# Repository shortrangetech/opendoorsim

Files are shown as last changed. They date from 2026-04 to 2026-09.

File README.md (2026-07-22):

# OpenDoorSim — Personal RFID Lab

<p align="center">
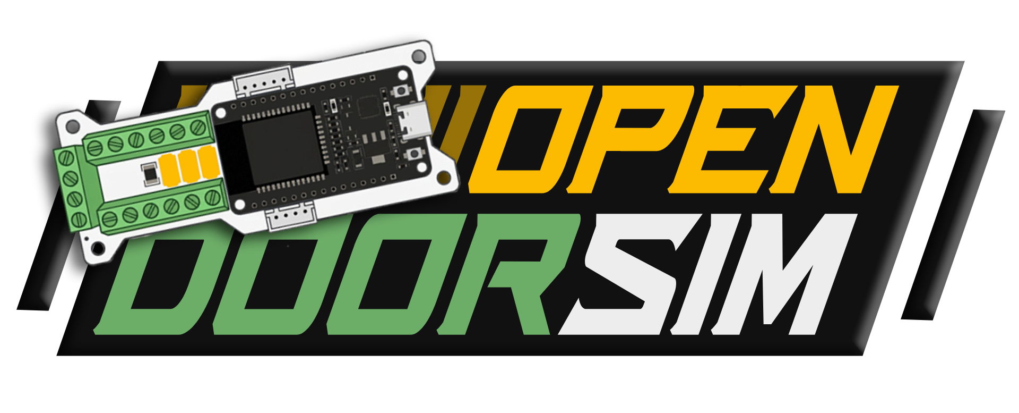
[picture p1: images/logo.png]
OpenDoorSim Logo
    
</p>

> [!NOTE]
> 
> 🚧 README and Documentation are under construction! Full documentation and links are being released incrementally through August. Check back for updates. 🚧

OpenDoorSim is your personal **open-source PACS / RFID lab!**. OpenDoorSim simulates Physical Access Control Systems (PACS) by connecting to real readers, so you can **hack the real thing!** At-home experiments, big CTFs, hands-on workshops, banger demos and advanced research are a breeze! It works with **any Wiegand or (soon) OSDP reader**, and fits easily in your bag. Sporting a **fresh web UI with a mirrored virtual display**, an **on-device hardware menu**, and multiple **modes** to make life easy, you may find it hard to put down... 

<p align="center">
  <a href="#">Documentation</a> · <a href="#">Build Guide</a> · <a href="#">Firmware Guide</a> · <a href="#">User Guide</a>
</p>
<p align="center">
  <a href="https://shortrange.tech">Support the Project - Buy an Official Kit!</a> · <a href="#">Self-Manufacture</a>
</p>

## Features

- Use any Wiegand or (soon) OSDP reader!
- Powered by 5V USB-C
- Beautiful Web UI for displaying data, managing users and modifying settings
- Handy on-device Menu for offline operations
- Multi Mode (Raw, User, Wifi, Stealth, Tamper Detect, etc)
- Live Virtual Display for easy demos
- Rugged 3D printed case
- Batch User Management

<p align="center">
  <a href="https://youtu.be/uSH2qY0MCnA">
    OpenDoorSim Demo Video<br>
    <sub>▶️ Click here to watch the demo video on YouTube</sub>
  </a>
</p>

## Quick start

For starters -- you'll need at minimum an OpenDoorSim (ODS) Board and a reader. You can manufacture your own PCBs using the project files, or buy an official PCB completely assembled and pre-flashed at [shortrange.tech](https://shortrange.tech). The card reader is up to you -- buy one from ebay, borrow one from work, etc...

Once you have an ODS board and reader, plug the reader's data and power lines into the board, and then power it via 5V USB-C. Connect to the OpenDoorSim's Wifi SSID and navigate to 192.168.8.8 to interact with the web UI. Now, you're ready to begin scanning!

You may want to add a physical screen, knob, and protective case to physically interact with your OpenDoorSim beyond the web UI. Upgrades, people! Again, you can purchase / build these yourself using the project files and Bill of Materials, or buy as part of an official kit. 

Once you have the parts you need from the BOM, follow the official [build guide](#).

For full details on the project, please visit the [Official Documentation](#).

Finally, make sure to tell your friends about the project!

<p align="center">
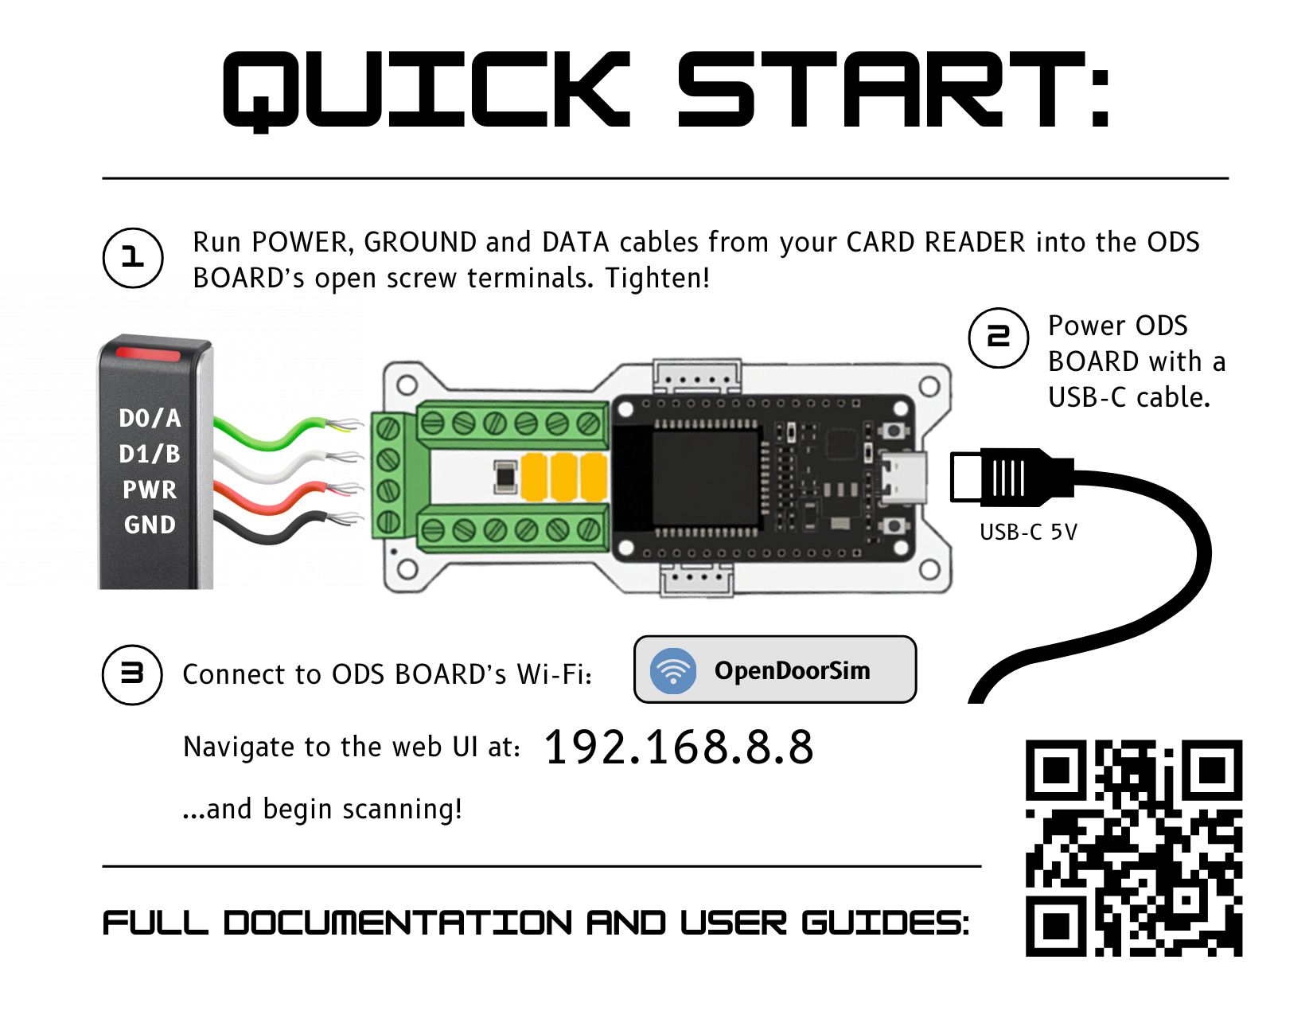
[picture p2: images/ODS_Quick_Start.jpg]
QuickStart Guide
    
</p>

## Support the Project

There are so many ways to support the project! Here are a few:
- Tell your friends about OpenDoorSim!
- Use your OpenDoorSim!
- Get your parts from the official BOM!
- Star the repository!
- Buy an [official kit!](https://shortrange.tech).

## Licenses and Agreements

This project is licensed under GPLv3.

**GPLv3 License**
This program is free software: you can freely use, modify, and distribute it. If you distribute your version, you must do so under the same GNU General Public License Version 3 (GPLv3) and include the source code. The software is provided without warranty, and the authors are not liable for damages.

See [LICENSE](LICENSE) for more details.

## Acknowledgments

This project was initially based on and greatly inspired by evildaemond's [DoorSim project](https://github.com/evildaemond/doorsim), without which this project would likely not exist, or at least have materialized nearly as soon as it did. 

Thanks to nechry for his [PlatformIO refactoring fork](https://github.com/nechry/DoorSim) of evildaemond's original DoorSim project. It was a great base to work from and LittleFS as well as PlatformIO really saved the day on development.  

A big thank you to the incredible students, hackers, professionals, and mentors in Iceman's Discord community [RFID Hacking By Iceman](https://discord.gg/F6wwKj6BHr), and to Iceman for his support. You all inspire me.  

Thank you to all other open source creators and mentors who are doing inspiring work in the field of PACS / RFID / RF! **Let's Hack The Planet!**

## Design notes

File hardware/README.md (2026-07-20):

# OpenDoorSim Hardware Guide

Welcome to the hardware folder for OpenDoorSim! This folder has the PCB manufacturing files, 3D models and schematics for the OpenDoorSim.

*For full instructions, please refer to the [Official Documentation](#).*

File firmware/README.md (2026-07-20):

# OpenDoorSim Firmware Guide

Welcome to the software folder for OpenDoorSim! The main firmware files live in this folder.

*For full instructions, please refer to the [Official Documentation](#).*

## Flashing Your OpenDoorSim's Firmware

OpenDoorSim's firmware can be flashed to your ESP32 device using the shell script (flash_board.sh) in the parent folder, or PlatformIO in your favorite IDE.

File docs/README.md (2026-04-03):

> [!NOTE]
> 🚧 This page is currently under construction. Check back soon!

This is the knowledge hub for the OpenDoorSim project that will contain BOMs, Tool Lists, build guides, and links to build videos.

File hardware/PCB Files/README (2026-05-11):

PCB FILES ARE CURRENTLY UNDERGOING A REWORK - THE CURRENT COMMUNITY DESIGN WILL LIKELY ONLY WORK WITH NEWER READERS WITH STRONG PULL-UP RESISTORS. NEW DESIGN COMING ASAP

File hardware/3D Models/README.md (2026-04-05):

# 3D Print Instructions
The following print instructions and settings are what I use for the official cases at [shortrange.tech](https://shortrange.tech). You may try to use materials other than ASA, however, please note that you will definitely need to change the settings if you are using a different material.

## My Personal Printer Setup

> [!NOTE]
> 
>Links below are affiliate links.
>If you purchase within 24hrs of clicking I may receive a small commission, which helps support the OpenDoorSim project at no extra cost to you. Thank you!

| Item | Details | Link |
| --- | --- | --- |
| Printer | Prusa Core One+ | Core One +: [Prusa3D](https://www.prusa3d.com/product/prusa-core-one-12/?p2p=%40shortrange_3431163)<br>Core One + Kit: [Prusa3D](https://www.prusa3d.com/product/prusa-core-one-kit-12/?p2p=%40shortrange_3431163)<br>or<br>**Use referral code @shortrange_3431163** for a free filament roll and extra prusameter reward points on any Prusa Printer.<br> |
| Print Plate | Prusa Textured Powder Coated Print Sheet | [Prusa3D](https://www.prusa3d.com/product/textured-powder-coated-print-sheet/) |
| Print Material | PolyMaker Fiberon ASA Carbon Fiber | 0.5kg Roll: [Amazon](https://amzn.to/4c1Yvve)<br>3kg Roll: [Amazon](https://amzn.to/4m8RcXg) |

## Slicer Settings
The slicer settings I use can be found below. I use PrusaSlicer. 

### Print Settings

| Print Setting | Value  |
| --- | --- |
| Layer Height  | 0.2mm  |
| Perimeters | 3 |
| Seam Position | Random |
| Infill | 15% |
| Fill Pattern  | Gyroid |

### Temperature Settings

| Temperature Setting  | Value |
| --- | ----- |
| Nozzle, First Layer  | 265 C |
| Nozzle, Other Layers | 265 C |
| Bed | 110 C |
| Chamber, Nominal | 55 C  |
| Chamber, Minimal | 40 C  |

### Cooling Settings

| Cooling Setting | Value |
| --- | --- |
| Bridges Fan Speed | 30% |
| Disable fan for the first | 5 layers |

### Modifier Settings
I place small modifier cubes around the following locations, for the following cases, with the following settings to help print stability and durability:

| Location | Setting | LAB | Pocket |
| --- | --- | --- | --- |
| Threaded Insert Holes, Surrounding Area | Cube, 100% Infill | ✅ | ✅ |
| Screw Head Holes, Surrounding Area | Cube, 100% Infill | ✅ | ✅ |
| USB-C Hole | Cube, Support Enforcer | ✅ | ✅ |
| Thin PCB Slot Below USB-C Hole, Internal | Cube, Support Enforcer | ✅ | ❌ |
| Through Strap "C" Slots, Surrounding and Supporting Areas | Cube, 100% Infill | ✅ | ❌ |
| Slider Side Arch | Cube, Support Enforcer | ❌ | ✅ |
| Encoder Hole | Cube, Support Enforcer | ❌ | ✅ |
| Horizontal Slider Pegs | Cube, Support Enforcer | ❌ | ✅ |

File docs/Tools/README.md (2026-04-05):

# My Personal Favorite Tools List
These are my personal tool kit favorites that I use **all the time** and recommend to everyone.

> [!NOTE]
> 
>Links below are affiliate links.
>If you purchase within 24hrs of clicking I may receive a small commission, which helps support the OpenDoorSim project at no extra cost to you. Thank you!

| Shortrange's Tools | Link |
| --- | --- |
| Portable Fast-Heating Soldering Iron (I know there are cheaper ones out there... but I love this one) | [Amazon](https://www.amazon.com/FNIRSI-Soldering-Temperature-Electronics-Precision/dp/B0DBLMH1HS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) |
| Wire Stripper | [Amazon](https://www.amazon.com/haisstronica-Stripper-Automatic-Crimping-Universal/dp/B0B2NWK1QX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) |
| Helping Hands | [Amazon](https://www.amazon.com/Helping-Soldering-Workshop-Non-slip-Weighted/dp/B07MDKXNPC/ref=sr_1_9?tag=shortrange-20) |
| Parts Mat | [Amazon](https://www.amazon.com/Kaisi-Insulation-Soldering-Maintenance-Electronics/dp/B073RFB6BX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) |
| Small Screwdriver Set | [Amazon](https://www.amazon.com/AXTH-Precision-Screwdriver-Professional-Electronic/dp/B0CBTYZY2S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) |

## My Personal Printer Setup

| Item | Details | Link |
| --- | --- | --- |
| Printer | Prusa Core One+ | Core One +: [Prusa3D](https://www.prusa3d.com/product/prusa-core-one-12/?p2p=%40shortrange_3431163)<br>Core One + Kit: [Prusa3D](https://www.prusa3d.com/product/prusa-core-one-kit-12/?p2p=%40shortrange_3431163)<br>or<br>**Use referral code @shortrange_3431163** for a free filament roll and extra prusameter reward points on any Prusa Printer.<br> |
| Print Plate | Prusa Textured Powder Coated Print Sheet | [Prusa3D](https://www.prusa3d.com/product/textured-powder-coated-print-sheet/) |
| Print Material | PolyMaker Fiberon ASA Carbon Fiber | 0.5kg Roll: [Amazon](https://amzn.to/4c1Yvve)<br>3kg Roll: [Amazon](https://amzn.to/4m8RcXg) |

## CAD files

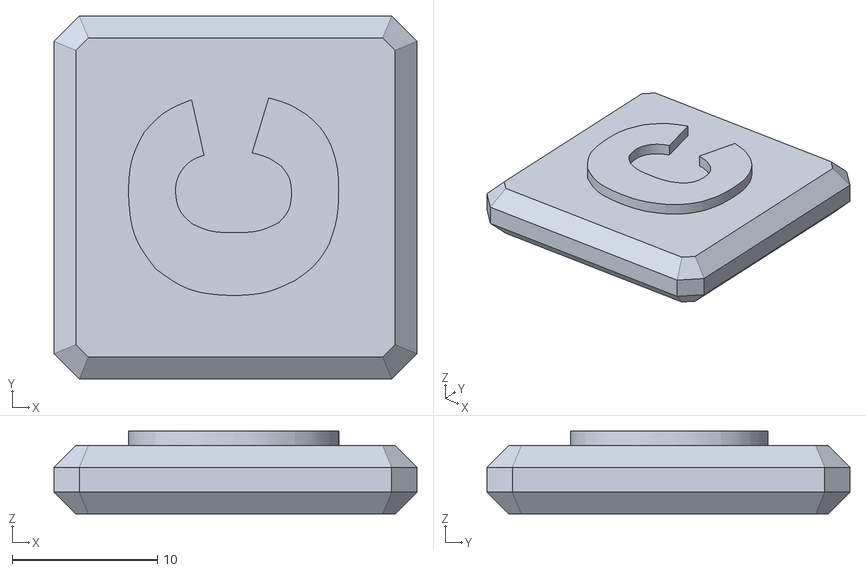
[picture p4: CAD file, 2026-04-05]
hardware/3D Models/LAB/Decal Tile/ODS_Lab_Decal_C.stl
25.0 x 25.0 x 5.70

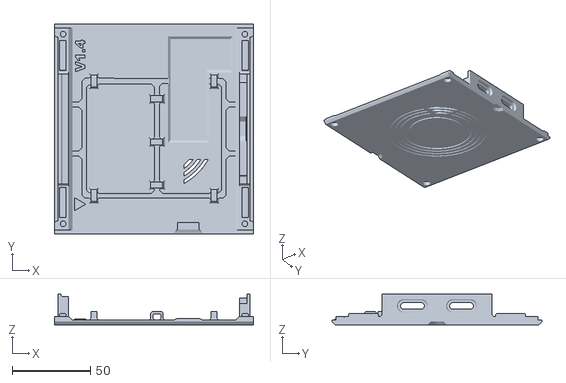
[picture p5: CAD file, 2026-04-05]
hardware/3D Models/LAB/ODS_Lab_Lid_Community_v1.4.stl
127.0 x 134.0 x 19.5

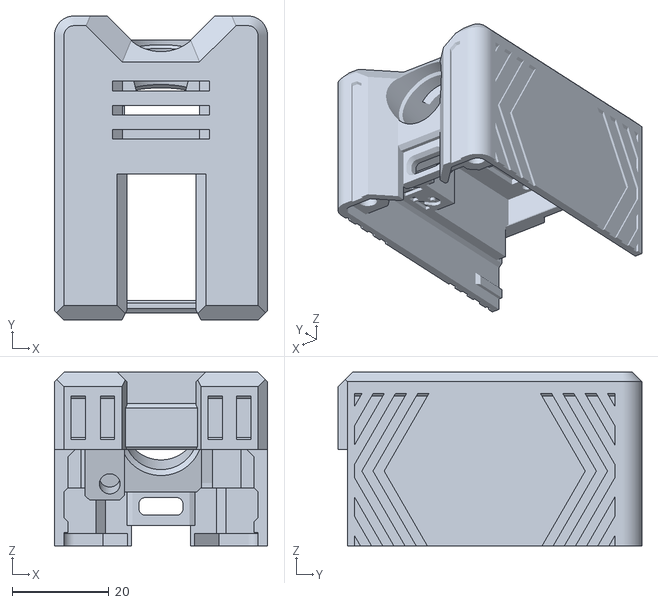
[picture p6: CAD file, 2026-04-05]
hardware/3D Models/Pocket/ODS_Pocket_Body_Community_v1.2.stl
44.2 x 62.9 x 36.0

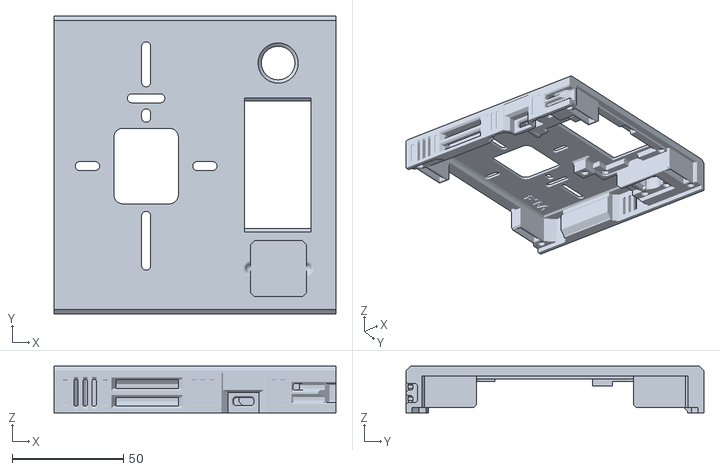
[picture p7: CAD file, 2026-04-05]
hardware/3D Models/LAB/ODS_Lab_Body_Community_v1.4.stl
127.0 x 134.0 x 21.0

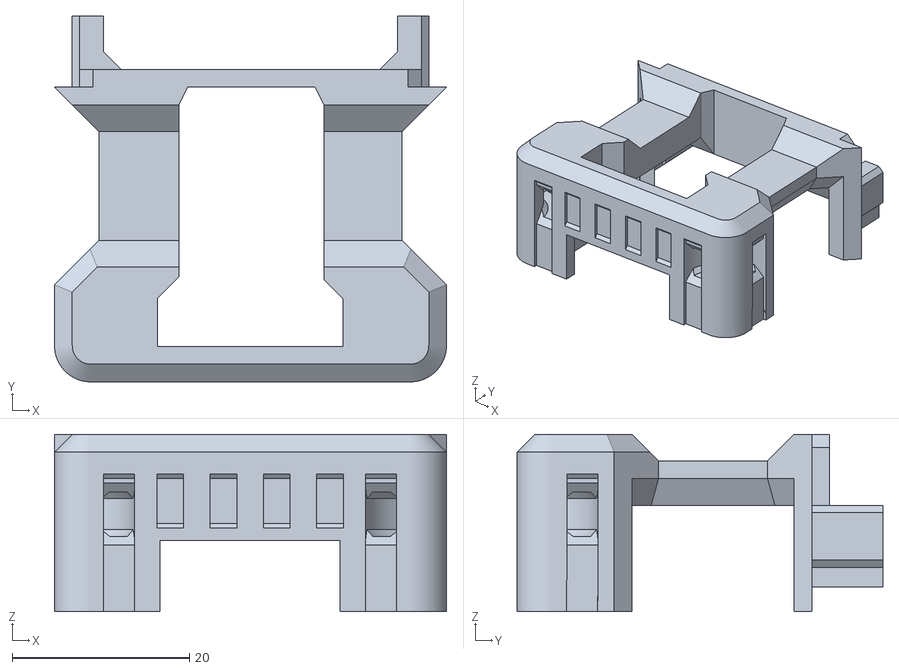
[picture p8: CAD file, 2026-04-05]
hardware/3D Models/Pocket/ODS_Pocket_Slider_Community_v1.2.stl
44.2 x 41.2 x 20.0

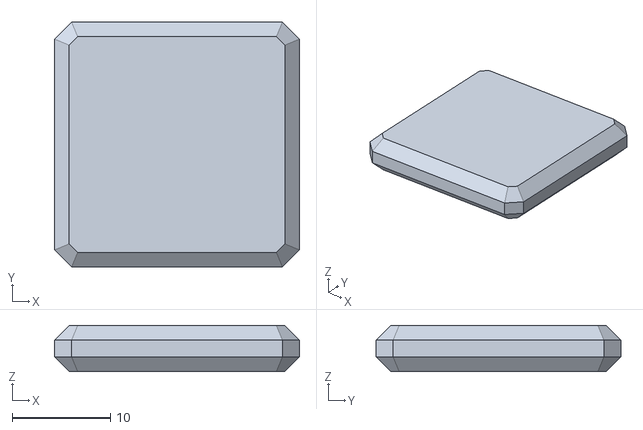
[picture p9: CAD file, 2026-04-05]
hardware/3D Models/LAB/Decal Tile/ODS_Lab_Decal_Blank_Community_v1.4.stl
25.0 x 25.0 x 4.70

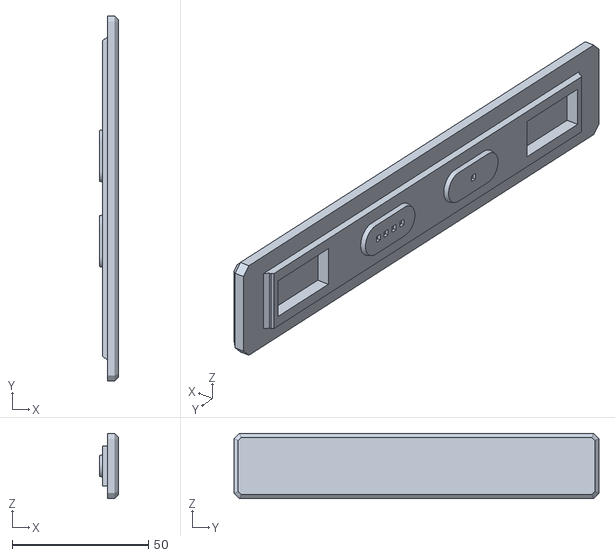
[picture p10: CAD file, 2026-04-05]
hardware/3D Models/LAB/ODS_Lab_Cap_Community_v1.4.stl
7.08 x 134.0 x 24.0

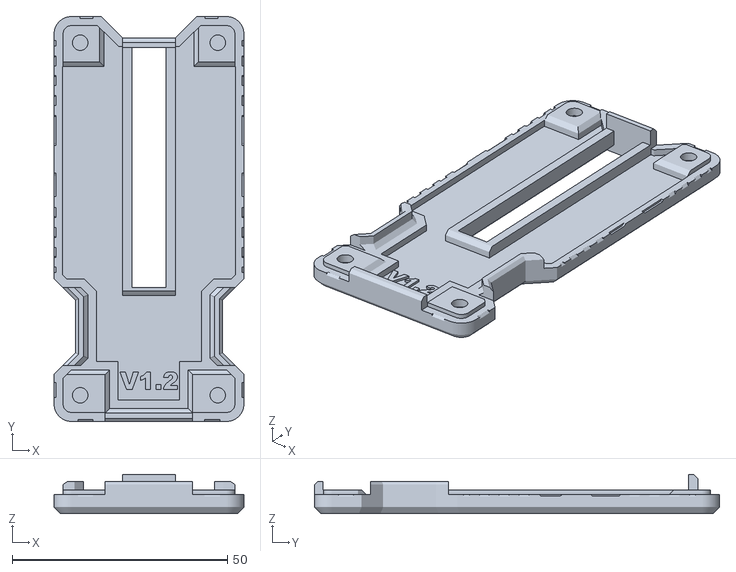
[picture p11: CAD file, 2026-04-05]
hardware/3D Models/Pocket/ODS_Pocket_Lid_Community_v1.2.stl
44.2 x 94.2 x 9.12

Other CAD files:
hardware/3D Models/LAB/Decal Tile/ODS_Lab_Decal_A.stl
hardware/3D Models/LAB/Decal Tile/ODS_Lab_Decal_B.stl

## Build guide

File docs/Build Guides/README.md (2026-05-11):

# Official Build Guides
This folder contains the official written build guides for OpenDoorSim LAB, Pocket, and Tarrific, as well as links to helpful corresponding videos.
## LAB and Pocket

| Resource                              |
| ------------------------------------- |
| Official Written Guide (Part 1, 2, 3) |
| [BUILD Tutorial Video (Part 1)](https://youtu.be/5gLYRzS1tTc)     |
| 🚧 ASSEMBLE Tutorial Video (Part 2)   |
| 🚧 FLASH Tutorial Video (Part 3)      |

## Tarrific

| Resource                     |
| ---------------------------- |
| 🚧 Written Guide coming soon |
| 🚧 Schematic coming soon     |

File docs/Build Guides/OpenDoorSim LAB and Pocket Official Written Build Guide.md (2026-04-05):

# OpenDoorSim Official Build Guide
This manual provides complete instructions for building your very own **OpenDoorSim LAB** or Pocket, assuming you have all parts on hand.  

| CONTENTS | Description |
| --- | --- |
| [BUILD The Board (Part 1)](#build-the-board-part-1) | Build and connect the main PCB with components. |
| [ASSEMBLE The OpenDoorSim (Part 2)](#assemble-the-opendoorsim-part-2) | Assemble the board and accessories into the final OpenDoorSim device. |
| [FLASH The Firmware (Part 3)](#flash-the-firmware-part-3) | Flash and test the microcontroller firmware. |

> [!TIP]
> 
>🚀 **SUPPORT THE PROJECT!**
>You can support the project by purchasing an official build kit [here](https://shortrange.tech) or by buying your own components through affiliate links at no extra cost to you. Or, just tell your friends about the project! Thank you for your support. ❤️ 

> [!NOTE]
> 
>Links below are affiliate links.
>If you purchase within 24hrs of clicking I may receive a small commission, which helps support the OpenDoorSim project at no extra cost to you. Thank you!

---

## BUILD The Board (Part 1)
This section contains instructions for building the main OpenDoorSim PCB, including core component connections and case fit preparation. 

### Bill of Materials
To complete Part 1 of the build, you will need the following tools and components. Depending on whether you're building the Lab or Pocket, you will need different components! 

| **Table Key:**  | |
| --- | --- |
| ✅ | Essential  |
| 🟡 | Optional |
| ❌ | Not Needed |

| **Tool**s | LAB | POCKET | Link |
| :--- | :-- | :----- | :--- |
| Soldering Iron | ✅ | ✅ | |
| Solder | ✅ | ✅ | |
| Wire Cutters | ✅ | ✅ | |
| Small Screwdriver | ✅ | ✅ | |
| Painter's Tape *(Optional)* | 🟡  | 🟡 | |
| Wire Strippers *(Optional)* | 🟡  | 🟡 | |
| Pliers *(Optional)* | 🟡  | 🟡 | |

| Quantity | Components | LAB | POCKET | Link |
| --- | --- | --- | --- | ---- |
| 1x | **OpenDoorSim PCB** | ✅ | ✅ | |
| 1x | **ESP-32 Microcontroller (30-Pin)** | ✅ | ✅ | |
| 6x | **Screw Terminal (2-Pin)** | ✅ | ✅ | |
| 1x | **KY-040 Encoder and Knob** | ✅ | ✅ | |
| 1x | **128x64 OLED, 2.42"** | ✅ | ❌ | |
| 9x | **Solid Core Wire, 100mm Long, 22awg** | ✅ | ❌ | |
| 1x | **128x64 OLED, 0.96"** | ❌ | ✅ | |
| 9x | **Solid Core Wire, 60mm Long, 22awg**  | ❌ | ✅ | |

> [!NOTE]
> 
>  I typically color scheme the 9x wire bundle as follows: 2x Red (Power), 2x Black (Ground), 2x Blue (Clock), 2x Yellow (Data), 1x Green (Switch)
> 

### Instructions

#### **Step 1: Microcontroller**

1. Align and insert the **ESP32** into the holes on the top of the PCB.
2. Optionally, secure the ESP32 flat against the board with tape.
3. Solder the **four corner pins** first to lock in alignment.
4. Ensure the ESP32 is completely flush with the PCB.
5. Solder the remaining pins.
6. Remove tape, excess solder.
#### **Step 2: Screw Terminal Blocks**

1. Pair up the 2 pin terminal blocks by sliding them together, making 3 sets.
2. Insert them into the designated holes on the PCB, facing out.
3. Optionally, secure with tape.
4. Solder the outside pins to lock in alignment.
5. Ensure the screw terminals are completely flush with the PCB.
6. Solder the remaining pins.
7. Remove tape, excess solder.

#### **Step 3: Wire Preparation**

1. Strip a small amount of insulation (~3-5mm) from both ends of the colored wires.

#### **Step 4: Wiring the PCB**

1. Thread the wires through the top of the OpenDoorSim PCB. There should be 4 OLED through holes, and 5 encoder through holes for a total of 9 wires. I suggest you follow the color-code standard below:
	- **Red:** Voltage (VCC/5V/3V).
	- **Black:** Ground (GND).
	- **Blue:** Clock (CLK).
	- **Yellow:** Data (SDA).
	- **Green:** Switch (SW).
2. Optionally, secure with tape.
3. Solder each wire to the board with a healthy bead of solder.
4. If desired, carefully add solder to the wire-side connection, avoiding the wire's own insulation. This "double bead" creates a stronger connection, helping avoid future wire snaps.
5. Remove tape, excess solder.
    
#### **Step 5: Preparing Accessories**

1. If your OLED screen or encoder has pre-installed pin headers, they must be removed for the wires to connect to them, and for the boards to fit in their precision casings.
2. To remove the pin headers, heat each pin with your iron and use pliers to gently wiggle and pull them out. This may take some patience!

#### **Step 6: Final Connections**

1. Thread the colored wires from the PCB into the corresponding screen and encoder components. 
	- ❗️Ensure wires are entering from the **underside** of the accessory boards. Otherwise, they will not fit in the case!
	- ❗️Note that the order of holes on the PCB is not necessarily the same order as your accessory's holes. Ensure that the correct connections are being made.
2. Optionally, use tape to secure the wires. 
3. Solder the wires to their component boards with a healthy bead of solder.
4. If desired, carefully add solder to the wire-side connection, avoiding the wire's own insulation. This "double bead" creates a stronger connection, helping avoid future wire snaps.
5. Remove tape, excess solder.
    
#### **Step 7: Clean Up Leads**

1. Use wire cutters to snip all excess component and wire leads on the bottom of the PCB and accessories.
2. Ensure all snips are flush to prevent shorts when the board is mounted in its casing.

### Final Thoughts

Congratulations on completing your OpenDoorSim board build! Give yourself a pat on the back, grab a snack, and get ready for part 2!

---

## ASSEMBLE The OpenDoorSim (Part 2)
This section contains instructions for putting everything together - preparing your incredible case, inserting magnets and threaded inserts, placing the board inside the case, and closing up the build!

> [!NOTE]
> 
>*If you want to make sure your board build works before putting it in the case, you may prefer to flash and test the board (Part 3) before assembling (Part 2). Otherwise, you may have to disassemble to troubleshoot properly. If that doesn't bother you, carry on!*

### Bill of Materials
To complete Part 2 of the build, you will need the following tools and components. Depending on whether you're building the Lab or Pocket, you will need different components! 

📈 **Table Key:**  
✅ Essential  
🟡 Optional  
❌ Not Needed  

| **Tool**s | LAB | POCKET | Link |
| :--- | :-- | :----- | :--- |
| Soldering Iron and/or Threaded Insert Press | ✅ | ✅ | |
| Small Screwdriver or General Tool for Poking and Scraping | ✅ | ✅ | |
| Allen Key, 2.5mm | ✅ | ✅ | |
| Allen Key, 1.5mm | ❌ | ✅ | |
| Thin String or Thread *(Optional. Necessary if you don't know the polarity of your magnets)* | ✅ | ❌ | |
| Super Glue, Commercial Strength *(Optional, Highly Recommended)* | 🟡  | 🟡 | |
| Super Glue Accelerator *(Optional, if you're impatient)* | 🟡  | 🟡 | |

| Quantity | Components | LAB | POCKET | Link |
| --- | --- | --- | --- | ---- |
| 1x | **ODS Lab Case (Body, Lid, 2x End Caps)** | ✅ | ❌ | |
| 1x | **ODS Pocket Case (Body, Slider, Lid)** | ❌ | ✅ | |
| 12x | **Threaded Insert, M3x4** | ✅ | ❌ | |
| 9x | **Screw, Hex Socket Head M3x6** | ✅ | ❌ | |
| 3x | **Screw, Hex Socket Head M3x4** | ✅ | ❌ | |
| 4x | **Neodymium Magnet, 20x10x5** | ✅ | ❌ | |
| 6x | **Neodymium Magnet, 20x10x3** | ✅ | ❌ | |
| 1x | **MagSafe Compatible Ring** | ✅ | ❌ | |
| 5x | **Threaded Insert, M3x4** | ❌ | ✅ | |
| 5x | **Screw, Hex Socket Head M3x6** | ❌ | ✅ | |
| 4x | **Threaded Insert, M2x3** | ❌ | ✅ | |
| 4x | **Screw, Hex Socket Head M2x4** | ❌ | ✅ | |
| 1x | **Key Ring, 20mm** | ❌ | ✅ | |
| 1x | **Carabiner, 33mm** | ❌ | ✅ | |
### Instructions

---
## Flash The Firmware (Part 3)

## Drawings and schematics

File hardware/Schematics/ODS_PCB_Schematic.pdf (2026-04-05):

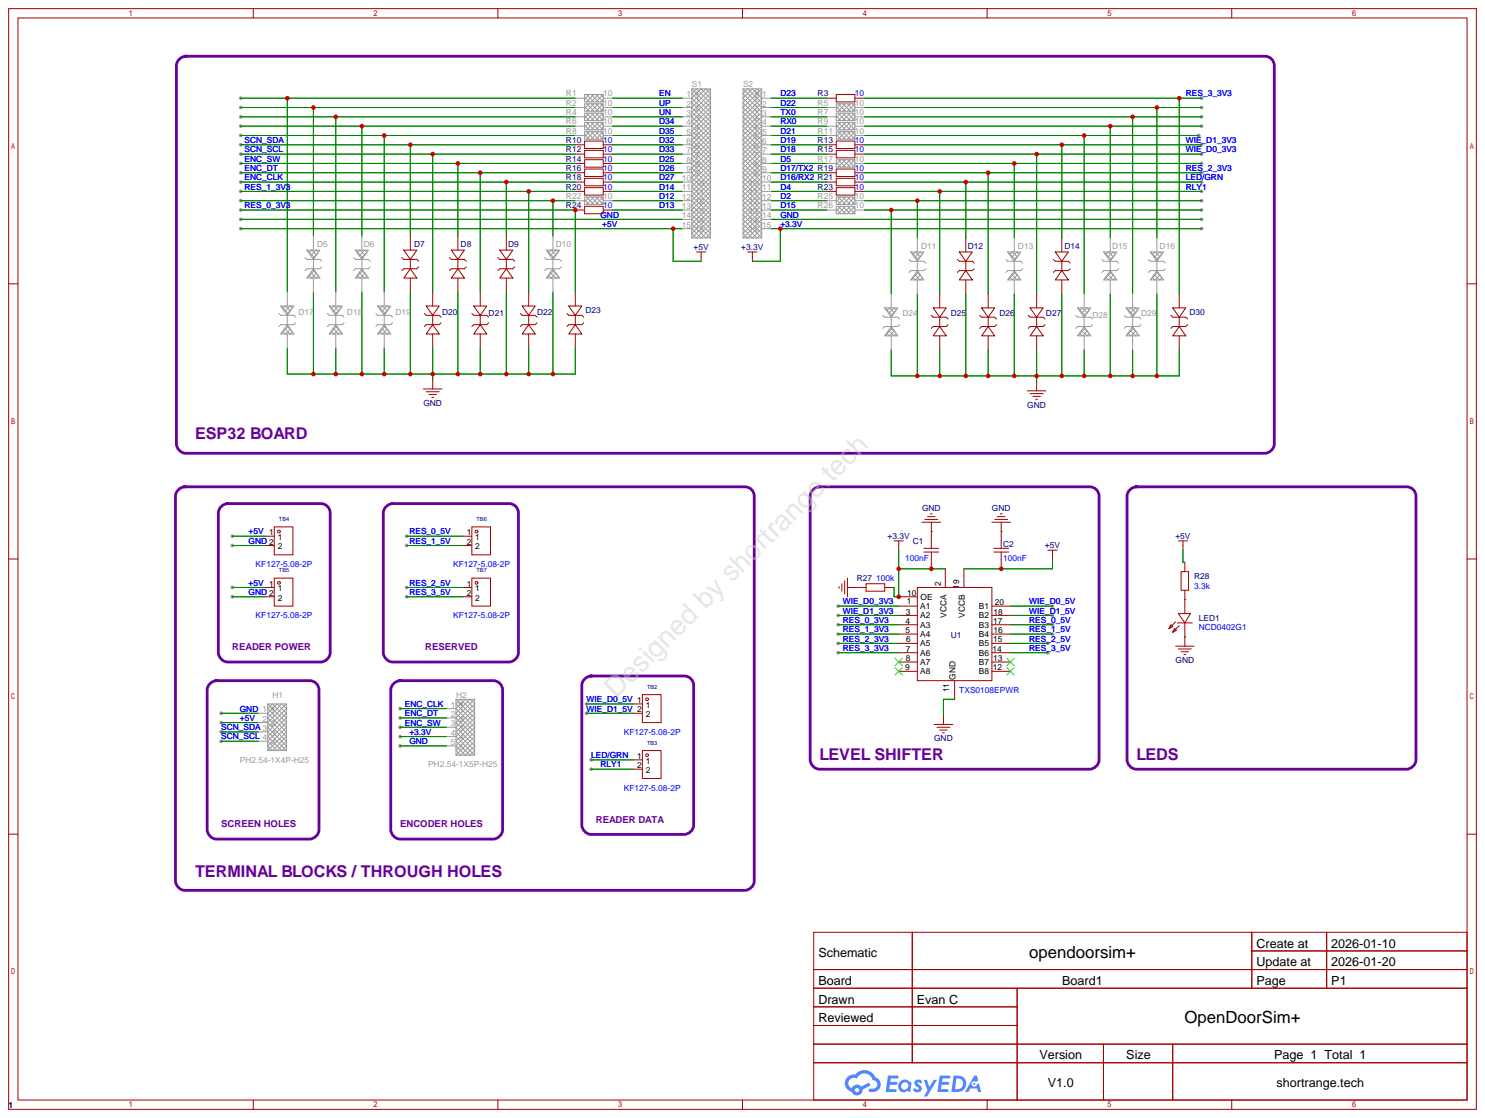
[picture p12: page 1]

Designed by shortrange.tech

TERMINAL BLOCKS / THROUGH HOLES

Schematic | opendoorsim+ | Create at | 2026-01-10

Update at | 2026-01-20

Board | Board1 | Page | P1
Drawn | Evan C | OpenDoorSim+
Reviewed

Version | Size | Page 1 Total 1
V1.0 | | shortrange.tech

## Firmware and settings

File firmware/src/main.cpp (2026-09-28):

#include "ArduinoJson.h"
#include "AsyncJson.h"
#include "ESPAsyncWebServer.h"
#include "nvs_flash.h"
#include <Adafruit_GFX.h>
#include <Adafruit_SSD1306.h>
#include <Arduino.h>
#include <AsyncTCP.h>
#include <DNSServer.h>
#include <LiquidCrystal_I2C.h>
#include <LittleFS.h>
#include <WiFi.h>
#include <Wire.h>

#include "opendoorsim.h"

// --- MENU SYSTEM CONSTANTS & STRUCTS ---

enum MenuState {
  STATE_STANDBY,
  STATE_MENU_NAV,
  STATE_MENU_EDIT,
  STATE_VIEW_LOG_LIST,
  STATE_VIEW_LOG_DETAIL,
  STATE_VIEW_WIFI_INFO,
  STATE_CONFIRM_REBOOT,
  STATE_CONFIRM_WIFI_REBOOT,
  STATE_CONFIRM_SCREEN_REBOOT,
  STATE_SYSTEM_PAUSED
};

// Types of menu items to determine how they are handled
enum MenuItemType {
  ITEM_SUBMENU, // Enters a new menu level
  ITEM_ACTION,  // Triggers a function (e.g., Reboot, Back)
  ITEM_TOGGLE,  // ON/OFF (bool)
  ITEM_SELECT,  // Cycle through predefined options (int/enum)
  ITEM_EXIT     // Returns to Standby
};

struct MenuItem {
  const char *label; // Text to display
  MenuItemType type;
  void *variable;    // Pointer to the variable being modified (optional)
  int minVal;        // For integer/select types
  int maxVal;        // For integer/select types
  MenuItem *submenu; // Pointer to child menu array (if SUBMENU)
  int submenuSize;   // Size of child menu array
};

// Global Menu State Variables
MenuState currentMenuState = STATE_STANDBY;
MenuItem *currentMenuLevel =
    nullptr;                 // Pointer to the current array of menu items
int currentMenuSize = 0;     // Number of items in current level
int selectedIndex = 0;       // Currently highlighted row
int scrollOffset = 0;        // For scrolling on small screens
int editTempIndex = 0;       // Temporary value holder during editing
int viewingCardIndex = -1;   // Which card from the log we are viewing
bool forceMenuUpdate = true; // Flag to force a redraw of the menu
bool origApMode = true;
int origSsidHidden = 0;

AsyncWebServer server(80);
AsyncEventSource events("/events");

IPAddress local_IP(192, 168, 8, 8);
IPAddress gateway(192, 168, 8, 8);
IPAddress subnet(255, 255, 255, 0);

const char *settingsFile = "/settings.json";
const char *usersFile = "/users.json";
const char *logFile = "/log.json";
const char *wiegandFormatsFile = "/wiegand_formats.json";

// I2C Screen Pins
#define SCN_SDA 32
#define SCN_CLK 33

// Rotary Encoder Pins
#define ENC_SW 25
#define ENC_DT 26
#define ENC_CLK 27

// Reader input pins
#define DATA0_PIN 34
#define DATA1_PIN 35
// optional, tamper detection relay
#define TMPR_PIN 21

// Reader output pins
#define LED_PIN 15

// System Command I2C (unused currently, reserved for future use)
#define SYS_I2C_SDA 21
#define SYS_I2C_CLK 22

// Accessory Ports (Extra GPIO Breakout Pins)
#define EX1_PIN 13
#define EX2_PIN 14
#define EX3_PIN 18
#define EX4_PIN 19
#define EX5_PIN 22
#define EX6_PIN 23

// Display type constants
#define DISPLAY_LCD 1
#define DISPLAY_OLED_64 2

// Display configuration constants
#define LCD_ADDRESS 0x27
#define LCD_COLUMNS 20
#define LCD_ROWS 4

#define OLED_RESET -1
#define OLED_ADDRESS 0x3C
#define OLED_WIDTH 128
#define OLED_HEIGHT 64

// Display objects - allocated at runtime based on active_display_type
LiquidCrystal_I2C *lcdDisplay = nullptr;
Adafruit_SSD1306 *oledDisplay = nullptr;

// Active display variable
// 1 for LCD, 2 for OLED 128x64
int activeDisplayType = DISPLAY_OLED_64;
bool flipOledDisplay = false;
int oledRotation =
    0; // Tracks the active hardware OLED rotation (0, 1, 2, or 3)

// general device settings
bool isCapturing = true;
String deviceMode = "user"; // "user" or "raw"
bool enableParityCheck = false;
int lastParityStatus = -1; // -1: disabled, 0: fail, 1: pass

// Tamper Relay Settings
bool enableTamperDetect = false;
bool tamperState = false;
unsigned long lastTamperCheck = 0;
const int TAMPER_CHECK_INTERVAL = 500; // milliseconds

// Reboot management
bool rebootRequested = false;
unsigned long rebootTimer = 0;
bool isSystemPaused = false; // Tracks if the scanner is paused

// --- ROTARY ENCODER VARIABLES ---
volatile int encoderCount = 0;
volatile unsigned long lastEncoderPress = 0;
const unsigned long DEBOUNCE_DELAY =
    150; // ms — covers mechanical bounce up to ~150ms
volatile unsigned long buttonPressStartTime =
    0; // records when button was first pressed
const unsigned long MIN_PRESS_DURATION =
    20; // ms — filters ghost pulses shorter than this
volatile bool encoderPressedFlag = false;
bool disableEncoder = false;

// State Machine Table
static const int8_t enc_states[] = {0,  -1, 1, 0, 1, 0, 0,  -1,
                                    -1, 0,  0, 1, 0, 1, -1, 0};
volatile uint8_t old_AB = 0; // Stores the previous pin state (0..3)

// Reader config and variables

// compile-time array size for bits (kept as a safe upper bound)
const int MAX_BITS_CONST = 200;
// runtime-configurable max bits (loaded from settings.json)
volatile unsigned int maxBits = MAX_BITS_CONST;
// time to wait for another weigand pulse (runtime-configurable)
volatile unsigned int weigandWaitTime = 30000; // orig 3000

// stores all of the data bits (sized to compile-time const)
volatile unsigned char databits[MAX_BITS_CONST];
volatile unsigned int bitCount = 0;

// stores the last written card's data bits
unsigned char lastWrittenDatabits[MAX_BITS_CONST];
unsigned int lastWrittenBitCount = 0;

// goes low when data is currently being captured
volatile unsigned char flagDone;

// countdown until we assume there are no more bits
volatile unsigned int weigandCounter;

// Display screen timer
unsigned long displayTimeout = 7000; // 7 seconds
unsigned long lastCardTime = 0;
bool displayingCard = false;
bool isSystemMessage = false;

// Wifi Settings
bool apMode = true;
// AP Settings
// ssid_hidden = broadcast ssid = 0, hidden = 1
// ap_passphrase = NULL for open, min 8 chars, max 63
String apSsid = "doorsim";
String apPwd;
int apChannel = 1;
int ssidHidden;
// TX Power index: 0=-1dBm, 1=2dBm, 2=5dBm, 3=8.5dBm, 4=13dBm
// Default is index 1 (2 dBm) — short-range for co-located boards
int apTxPower = 1;

// LED Flash Green on Valid Setting 0 (None), 1 (Rapid Flash), 2 (Long Flash)
int ledValid = 1;

// Custom Display Message
String customMessage = "     OPENDOORSIM     ";
String firmwareVersion = "v1.1";

// decoded facility code and card code
unsigned long facilityCode = 0;
unsigned long cardNumber = 0;
bool hasFormat = false;

// raw data string (fixed buffers)
char rawCardData[RAW_DATA_MAX];
char status[STATUS_MAX];
char details[DETAILS_MAX];
char lastHexData[HEX_DATA_MAX];
int lastPadCount = 0;

const int MAX_USERS = 100;
User users[MAX_USERS];
int userCount = 0;

// maximum number of stored cards
const int MAX_CARDS = 25;
CardData cardDataArray[MAX_CARDS];
int cardDataIndex = 0;
bool pendingLogSave = false;

// Wiegand formats
const int MAX_WIEGAND_FORMATS = 50;
WiegandFormat wiegandFormats[MAX_WIEGAND_FORMATS];
int wiegandFormatCounter = 0;

int tempDeviceModeInt = 0;
int tempTimeoutIndex = 0;
bool origFlipOled = false; // Captures flipOledDisplay on GENERAL submenu entry

// --- MENU ARRAYS ---

// 1. User Submenu
MenuItem menuItems_User[] = {
    {"Back", ITEM_ACTION, nullptr, 0, 0, nullptr, 0},
    {"Valid LED", ITEM_SELECT, &ledValid, 0, 2, nullptr,
     0} // 0=None, 1=Rapid, 2=Long
};

// 2. Wifi Submenu
MenuItem menuItems_Wifi[] = {
    {"Back", ITEM_ACTION, nullptr, 0, 0, nullptr, 0},
    {"Access Point", ITEM_TOGGLE, &apMode, 0, 1, nullptr, 0},
    {"Hidden", ITEM_TOGGLE, &ssidHidden, 0, 1, nullptr, 0},
    {"View Info", ITEM_ACTION, nullptr, 0, 0, nullptr, 0}};

// 3. General Submenu
// 3a. Display Submenu
MenuItem menuItems_Display[] = {
    {"Back", ITEM_ACTION, nullptr, 0, 0, nullptr, 0},
    {"Timeout", ITEM_SELECT, &tempTimeoutIndex, 0, 5, nullptr, 0},
    {"Flip Screen", ITEM_TOGGLE, &flipOledDisplay, 0, 1, nullptr, 0}};

// 3. General Submenu
MenuItem menuItems_General[] = {
    {"Back", ITEM_ACTION, nullptr, 0, 0, nullptr, 0},
    {"Mode", ITEM_SELECT, &tempDeviceModeInt, 0, 1, nullptr, 0},
    {"Parity Chk", ITEM_TOGGLE, &enableParityCheck, 0, 1, nullptr, 0},
    {"Tamper", ITEM_TOGGLE, &enableTamperDetect, 0, 1, nullptr, 0}};

// 4. Main Menu
MenuItem menuItems_Main[] = {
    {"Return to Doorsim", ITEM_EXIT, nullptr, 0, 0, nullptr, 0},
    {"VIEW DATA", ITEM_ACTION, nullptr, 0, 0, nullptr, 0},
    {"GENERAL", ITEM_SUBMENU, nullptr, 0, 0, menuItems_General, 0},
    {"DISPLAY", ITEM_SUBMENU, nullptr, 0, 0, menuItems_Display, 0},
    {"WIFI", ITEM_SUBMENU, nullptr, 0, 0, menuItems_Wifi, 0},
    {"USER MODE", ITEM_SUBMENU, nullptr, 0, 0, menuItems_User, 0},
    {"REBOOT", ITEM_ACTION, nullptr, 0, 0, nullptr, 0}};

void IRAM_ATTR isr_rotary() {
  if (isSystemPaused)
    return;
  uint8_t new_AB = (digitalRead(ENC_CLK) << 1) | digitalRead(ENC_DT);

  // Combine old state and new state to create the index for our table
  // Index = (old_AB * 4) + new_AB
  // We mask with 0x0f (15) just to be safe, though logically unnecessary if
  // old_AB is 2 bits.
  old_AB &= 0x03; // ensure old_AB is only 2 bits
  int stateIndex = (old_AB << 2) | new_AB;

  // Add the table value to the count
  encoderCount += enc_states[stateIndex];

  // Update old state for next time
  old_AB = new_AB;
}

void IRAM_ATTR isr_button() {
  if (isSystemPaused)
    return;
  if (encoderPressedFlag)
    return;

  unsigned long now = millis();
  if (digitalRead(ENC_SW) == LOW) {
    if (now - lastEncoderPress > DEBOUNCE_DELAY) {
      encoderPressedFlag = true;
      lastEncoderPress = now;
      buttonPressStartTime = now; // record when the press began
    }
  }
}

void setupEncoder() {
  // Use Internal Pullups
  pinMode(ENC_CLK, INPUT_PULLUP);
  pinMode(ENC_DT, INPUT_PULLUP);
  pinMode(ENC_SW, INPUT_PULLUP);

  // Initialize the state variable immediately so we don't start with a jump
  old_AB = (digitalRead(ENC_CLK) << 1) | digitalRead(ENC_DT);

  // Attach interrupts to BOTH pins on CHANGE
  attachInterrupt(digitalPinToInterrupt(ENC_CLK), isr_rotary, CHANGE);
  attachInterrupt(digitalPinToInterrupt(ENC_DT), isr_rotary, CHANGE);

  // Button remains the same
  attachInterrupt(digitalPinToInterrupt(ENC_SW), isr_button, FALLING);
}

// FORWARD DECLARATION (Fixes the error)
void processMenuAction();
void updateDisplay(); // Ensure this is also known if not already

void handleMenuInput() {

  // check for encoder disabled
  if (disableEncoder && currentMenuState == STATE_STANDBY) {
    // Reset flags so they don't pile up
    encoderCount = 0;
    encoderPressedFlag = false;
    return;
  }

  if (encoderCount != 0) {
    // RESOLUTION ADJUSTMENT:
    // Most encoders have 4 "steps" per physical detent/click.
    // We only move the menu if we have accumulated enough steps.
    // Try dividing by 4 first. If it feels too slow, change to 2.
    int steps = encoderCount / 4;

    if (steps != 0) {

      displayingCard = false;
      encoderCount -= (steps * 4);

      if (currentMenuState == STATE_MENU_EDIT) {
        editTempIndex += steps;
        MenuItem *item = &currentMenuLevel[selectedIndex];
        if (editTempIndex < item->minVal)
          editTempIndex = item->minVal;
        if (editTempIndex > item->maxVal)
          editTempIndex = item->maxVal;
        forceMenuUpdate = true;
      } else if (currentMenuState == STATE_MENU_NAV ||
                 currentMenuState == STATE_VIEW_LOG_LIST) {
        selectedIndex += steps;
        int maxIndex = (currentMenuState == STATE_VIEW_LOG_LIST)
                           ? cardDataIndex
                           : (currentMenuSize - 1);

        // Wrap-around or Clamp logic?
        // Currently clamping:
        if (maxIndex < 0)
          maxIndex = 0;
        if (selectedIndex < 0)
          selectedIndex = 0;
        if (selectedIndex > maxIndex)
          selectedIndex = maxIndex;

        forceMenuUpdate = true;
      } else if (currentMenuState == STATE_CONFIRM_REBOOT) {
        currentMenuState = STATE_MENU_NAV;
        forceMenuUpdate = true;
      } else if (currentMenuState == STATE_CONFIRM_WIFI_REBOOT) {
        apMode = origApMode;
        ssidHidden = origSsidHidden;
        currentMenuState = STATE_MENU_NAV;
        currentMenuLevel = menuItems_Main;
        currentMenuSize = sizeof(menuItems_Main) / sizeof(menuItems_Main[0]);
        selectedIndex = 4;
        scrollOffset = 0;
        forceMenuUpdate = true;
      } else if (currentMenuState == STATE_CONFIRM_SCREEN_REBOOT) {
        flipOledDisplay = origFlipOled; // Revert the toggle
        currentMenuState = STATE_MENU_NAV;
        currentMenuLevel = menuItems_Main;
        currentMenuSize = sizeof(menuItems_Main) / sizeof(menuItems_Main[0]);
        selectedIndex = 3;
        scrollOffset = 0;
        forceMenuUpdate = true;
      }

      updateDisplay();
    }
  }

  if (encoderPressedFlag) {
    // Check if the button is released
    if (digitalRead(ENC_SW) == HIGH) {

      // Minimum press duration guard: discard ghost pulses that were never
      // really held (e.g. a bounce that briefly pulled the pin LOW).
      if (millis() - buttonPressStartTime < MIN_PRESS_DURATION) {
        encoderPressedFlag = false;  // Discard — not a real press
        lastEncoderPress = millis(); // reset debounce timer from release point
        return;
      }

      processMenuAction();
      forceMenuUpdate = true;

      // Unlock ISR — reset debounce timer from release moment so that
      // release-bounce FALLING edges (which occur > 150ms after press start
      // on a long hold) don't slip through as a second click.
      lastEncoderPress = millis();
      encoderPressedFlag = false;
    }
  }
}

int getVisibleRows() {
  if (activeDisplayType == DISPLAY_LCD)
    return 4;
  if (activeDisplayType == DISPLAY_OLED_64)
    return 4; // setTextSize(1,2) = 16px tall chars, 4 lines fill 64px
  return 4;
}

void drawTextLine(int row, String text, bool inverted = false) {
  int yPos = 0;

  if (activeDisplayType == DISPLAY_LCD && lcdDisplay != nullptr) {
    if (row >= 4)
      return; // LCD only has 4 rows
    lcdDisplay->setCursor(0, row);
    // LCD can't really "invert" text easily without custom chars,
    // so we mark selected lines with a ">" character instead.
    if (inverted)
      lcdDisplay->print(">");
    else
      lcdDisplay->print(" ");

    // Print text, trimming if too long
    if (text.length() > 19)
      text = text.substring(0, 19);
    lcdDisplay->print(text);

    // Clear rest of line
    for (int i = text.length() + 1; i < 20; i++)
      lcdDisplay->print(" ");
  }

  else if (activeDisplayType == DISPLAY_OLED_64 && oledDisplay != nullptr) {
    yPos = row * 16; // setTextSize(1,2) = 16px per row, 4 rows fill 64px

    if (inverted) {
      oledDisplay->setTextColor(SSD1306_BLACK,
                                SSD1306_WHITE); // Draw black text on white bg
      // Draw background bar
      oledDisplay->fillRect(0, yPos, OLED_WIDTH, 16, SSD1306_WHITE);
    } else {
      oledDisplay->setTextColor(SSD1306_WHITE);
    }

    oledDisplay->setTextSize(1, 2);
    oledDisplay->setCursor(0, yPos);
    oledDisplay->println(text);
  }
}

void renderMenu() {
  // OLEDs clear the whole buffer first, so they don't have this issue.
  if (activeDisplayType != DISPLAY_LCD)
    oledDisplay->clearDisplay();

  int visibleRows = getVisibleRows();

  // Calculate Scroll Offset
  if (selectedIndex < scrollOffset) {
    scrollOffset = selectedIndex;
  } else if (selectedIndex >= scrollOffset + visibleRows) {
    scrollOffset = selectedIndex - visibleRows + 1;
  }

  // Draw Items
  for (int i = 0; i < visibleRows; i++) {
    int itemIndex = scrollOffset + i;

    // --- FIX START: CLEAR UNUSED ROWS ---
    // Instead of 'break', we explicitly draw a blank line to wipe old text.
    if (itemIndex >= currentMenuSize) {
      drawTextLine(i, "");
      continue;
    }
    // --- FIX END ---

    MenuItem *item = &currentMenuLevel[itemIndex];
    String label = String(item->label);

    // Helper to show current values for Select/Toggle items
    if (item->type == ITEM_TOGGLE && item->variable != nullptr) {
      bool val = *(bool *)item->variable;
      label += ": " + String(val ? "ON" : "OFF");
    } else if (item->type == ITEM_SELECT && item->variable != nullptr) {
      int val = *(int *)item->variable;
      // Special handling for editing state
      if (currentMenuState == STATE_MENU_EDIT && itemIndex == selectedIndex) {
        val = editTempIndex; // Show the temporary value we are scrolling
      }
      if (String(item->label) == "Mode") {
        label += ": " + String(val == 0 ? "RAW" : "USER");
      } else if (String(item->label) == "Timeout") {
        String tStr;
        switch (val) {
        case 0:
          tStr = "None";
          break;
        case 1:
          tStr = "5s";
          break;
        case 2:
          tStr = "7s";
          break;
        case 3:
          tStr = "15s";
          break;
        case 4:
          tStr = "20s";
          break;
        case 5:
          tStr = "30s";
          break;
        default:
          tStr = String(val);
        }
        label += ": " + tStr;
      } else if (String(item->label) == "Valid LED") {
        String lStr;
        switch (val) {
        case 0:
          lStr = "None";
          break;
        case 1:
          lStr = "Rapid";
          break;
        case 2:
          lStr = "Long";
          break;
        default:
          lStr = String(val);
        }
        label += ": " + lStr;
      } else {
        label += ": " + String(val);
      }
    }

    // Draw the line
    bool isSelected = (itemIndex == selectedIndex);

    // LCD Specific: Add indicator chars to the string
    if (activeDisplayType == DISPLAY_LCD) {
      if (currentMenuState == STATE_MENU_EDIT && isSelected) {
        // visual cue for editing
        if (isSelected)
          label = (currentMenuState == STATE_MENU_EDIT) ? "*" + label : label;
      }
    } else {
      // OLED visual cue
      if (currentMenuState == STATE_MENU_EDIT && isSelected)
        label = "*" + label;
    }

    drawTextLine(i, label, isSelected);
  }

  if (activeDisplayType != DISPLAY_LCD)
    oledDisplay->display();
}

void renderCardLogList() {
  // OLEDs use a buffer, so we can clear the whole thing first.
  if (activeDisplayType != DISPLAY_LCD)
    oledDisplay->clearDisplay();

  int visibleRows = getVisibleRows();
  // Total rows = All cards + 1 for the "Back" button at top
  int totalRows = cardDataIndex + 1;

  // Calculate Scroll Offset
  if (selectedIndex < scrollOffset) {
    scrollOffset = selectedIndex;
  } else if (selectedIndex >= scrollOffset + visibleRows) {
    scrollOffset = selectedIndex - visibleRows + 1;
  }

  for (int i = 0; i < visibleRows; i++) {
    int actualIndex = scrollOffset + i;

    // --- CHANGED HERE ---
    // Instead of breaking if we run out of data, we explicitly draw a blank
    // line. This wipes any "ghost" text from the previous menu screen on LCDs.
    if (actualIndex >= totalRows) {
      drawTextLine(i, "");
      continue;
    }

    // --- TOP ITEM IS BACK BUTTON ---
    if (actualIndex == 0) {
      drawTextLine(i, "Back", (actualIndex == selectedIndex));
    }
    // --- ALL OTHER ITEMS ARE CARDS ---
    else {
      // Map list index to array index.
      // List Index 1 = Newest Card (cardDataArray[cardDataIndex - 1])
      int dataIdx = cardDataIndex - actualIndex;

      // 1. Build Prefix
      String prefix = String(cardDataArray[dataIdx].bitCount) + "b ";

      // 2. Get Hex
      String hex = String(cardDataArray[dataIdx].hexData);

      // 3. Dynamic Fit Calculation
      // LCD Width (20) - Selection Cursor (1) = 19 Max Content Width
      int maxContentWidth = 19;
      int availableSpace = maxContentWidth - prefix.length();

      // 4. Truncate if needed
      if (hex.length() > availableSpace) {
        // Cut string to fit, reserving room for ".."
        hex = hex.substring(0, availableSpace - 2) + "..";
      }

      // 5. Combine and Draw
      String rowText = prefix + hex;
      drawTextLine(i, rowText, (actualIndex == selectedIndex));
    }
  }

  if (activeDisplayType != DISPLAY_LCD)
    oledDisplay->display();
}

// Interrupts for card reader
void IRAM_ATTR ISR_INT0() {
  if (isSystemPaused)
    return;
  // FIX: Ignore interrupts if we are not in standby (e.g. using menu)
  if (currentMenuState != STATE_STANDBY)
    return;

  // DATA0 pulse represents a 0 bit
  if (bitCount < maxBits) {
    databits[bitCount] = 0;
    bitCount++;
  }
  flagDone = 0;
  // Reset the wait timer
  weigandCounter = weigandWaitTime;
}
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
void loop() {
  handleMenuInput();

  if (rebootRequested) {
    if (millis() - rebootTimer > 1000) {
      Serial.println("[SYSTEM] Rebooting now...");
      ESP.restart();
    }
    return;
  }

  if (enableTamperDetect) {
    checkTamper();
  }

  updateDisplay();

  // FIX: strictly wrap ALL card processing logic inside STATE_STANDBY check
  if (currentMenuState == STATE_STANDBY) {

    // Countdown timer logic
    if (!flagDone) {
      if (--weigandCounter == 0) {
        flagDone = 1; // No more data expected
        Serial.println("[LOOP] Weigand transmission complete.");
      }
    }

    // Check if the card reader has finished reading data
    if (bitCount > 0 && flagDone) {
      // Indicate that a card is being displayed
      displayingCard = true;

      // Ensure the data is valid (not all bits are 1s)
      if (!allBitsAreOnes() && !allBitsAreZeros()) {
        // Process the card data
        processCardData();

        forceMenuUpdate = false;
        if (bitCount >= 12 && bitCount <= MAX_BITS_CONST) {
          printCardData();
          printCardDataSerial();
        }
      }
      cleanupCardData();
      clearDatabits();
    }
  }

  // Check if we need to save the log persistently
  if (pendingLogSave) {
    saveLogToPreferences();
    pendingLogSave = false;
  }
}

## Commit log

2025-11-22 Pin setup
2025-11-23 removed hex interrupts, outputs, and repetitive blocking
2025-11-23 added flag var. fixed LCD address. simplified customBanner logic.
    [main.cpp]
2025-11-26 small setCursor bug fixed, oled now works
    [main.cpp]
2025-12-06 LED and flashes work. Tamper detection works. Need to test raw mode.
2025-12-17 made CTF mode default page. fixed wifi crashes for too short password. fixed reboot loop.
    [main.cpp]
2025-12-18 added reboot button. changed default ip to 192.168.8.8
    [main.cpp]
2025-12-20 v0.8.5 - disable tamper detect by default. updated i2c screen and wiegand pins for new layout. implemented oled flip. added more display timeout options. added show/hide current password option.
    [main.cpp]
2025-12-21 fixed oled initiation issues, reserved small text with status bar (tall) 128x64 option for a future TODO
    [main.cpp]
2025-12-21 fixed rotary encoder pinout
    [main.cpp]
2025-12-25 fixed rendercardloglist() to display data correctly in knob menu, force menu update
    [main.cpp]
2025-12-25 fixed lines not updating on renderCardLogList()
    [main.cpp]
2025-12-25 fixed reboot and view info, fixed interrupt so menu displays immediately upon knob press rather than waiting for the card display timeout.
    [main.cpp]
2025-12-28 fixed hardware menu to reboot on wifi settings change. reboot actually works. wifi off actually works. fixed reboot loop.
    [main.cpp]
2025-12-28 fixed ctf menu being too long. small text fixes.
    [main.cpp]
2025-12-28 LED none, rapid, long settings added in CTF submenu.
2025-12-28 fixed encoder menu variables not updated on webserver settings save, and vice versa. settings changed on either side should now post to global vars and immediately propagate to the other side.
    [main.cpp]
2025-12-28 fixed "None" and other settings not propagating.
    [main.cpp]
2025-12-29 adjusted text styling so it is consistent across platforms. adjusted opacity of clickable badges, fixed border flash on filter change.
2025-12-30 added "disable encoder" option to disable rotary encoder menu when running ctf's to avoid user interference / unintended solves.
    [main.cpp]
2025-12-30 v0.8.8 Doorsim Pause Option Added, fully functional, prevents interrupts from firing to regulate broken CTF modules. navbar size adjustments. fixed system popups sometimes not clearing.
    [main.cpp]
2026-04-05 changed oled to default active display w in settings, all 3d printer settings and files added
    [ODS_Lab_Body_Community_v1.4.stl, ODS_Lab_Cap_Community_v1.4.stl, ODS_Lab_Decal_A.stl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]
2026-04-05 PCB files
    [ODS_Community_PCB_BOM.csv, ODS_Community_PCB_Pick_and_Place.csv]
2026-04-05 Printer Table Adjustments
2026-04-09 Add README for PCB files rework status
    The README file indicates that PCB files are being reworked and may only function with newer readers that have strong pull-up resistors.
2026-05-11 changed pins for new board design, flipped LED logic for mosfet
    [ODS_Community_PCB_BOM.csv, ODS_Community_PCB_Pick_and_Place.csv]
2026-05-11 fixed long press encoder issue, modified debounce and interrupts
    [main.cpp]
2026-06-27 fix: actually added the upright screen
    [main.cpp]
2026-06-27 flipped logic for hardware screen and default in main so that it would start out of the box upright on the lab edition
    [main.cpp]
2026-06-28 implemented screen flip toggle in hardware menu
    [main.cpp]
2026-06-28 fixed DEBOUNCE weird clicking issue!!
    [main.cpp]
2026-06-28 fix: ENCODER adjusted to solve double click bug in menu, reset debounce window from release point
    [main.cpp]
2026-06-28 v0.9.0 - screen, encoder functionality, quality of life, code refactoring improvements
2026-06-29 fixed virtual screen to have four lines
    [main.cpp]
2026-06-29 MODE toggle functionality moved to the navbar indicator. fixed screen refresh.
    [main.cpp]
2026-06-29 finalized toggle button, fixed fading errors and grow effect
2026-07-08 fixed rename out of bounds menu USER MODE selection
    [main.cpp]
2026-07-08 fixed edit user bug. fixed name population delay in table
    [main.cpp]
2026-07-08 cache busting to fix add and delete user bugs
    [main.cpp]
2026-07-08 added clear users function. moved pause and restart buttons to the navbar.
2026-07-08 quick add user button added
2026-07-09 grow / shrink animation for badges and buttons changing size, color adjustments, fix on parity badges actually working, stopped mode button bug click on paused mode. better animations but not quite f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
2026-07-09 mode button shrinks correctly now. PAD text moved inside data badge. fixed grow / shrink animation of clickable data badge
2026-07-09 moved parity check setting from settings page to navbar button.
2026-07-09 fixed CSS / look of parity toggle button in navbar
2026-07-09 enable disable encoder button moved to navbar
2026-07-09 navbar button look fixed
2026-07-09 Enable encoder when wifi ap disabbled to prevent lockout
    [main.cpp]
2026-07-09 fixed enable encoder when booting up and ap disabled
    [main.cpp]
2026-07-09 tamper nav bug race condition fixed
    [main.cpp]
2026-07-09 PING switch from polling! WAY faster updates in card reads and icons now!
2026-07-10 mode button moved down
2026-07-10 added cancel button
2026-07-10 remove config settings saved message when simply switching mode between user / raw.
2026-07-10 v1.1 LETS GOO bconfimed encoder screen online works with or without accessories
2026-07-12 flash board script!
2026-09-28 added missing PnP file. Advanced Flash Mode beta, added wifi channel and strength selection options.
    [ODS_PCB_v2.2_PNP_Community.csv]
